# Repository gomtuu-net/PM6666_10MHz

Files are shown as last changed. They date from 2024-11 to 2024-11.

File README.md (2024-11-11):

# 10MHz OCXO for Philips/Fluke PM6666 counter
Alternative 10MHz oscillator for Philips/Fluke PM6665 and PM6666 frequency counters.

[Schematic](https://github.com/gomtuu-net/PM6666_10MHz/blob/master/PM6666-10MHz.pdf)

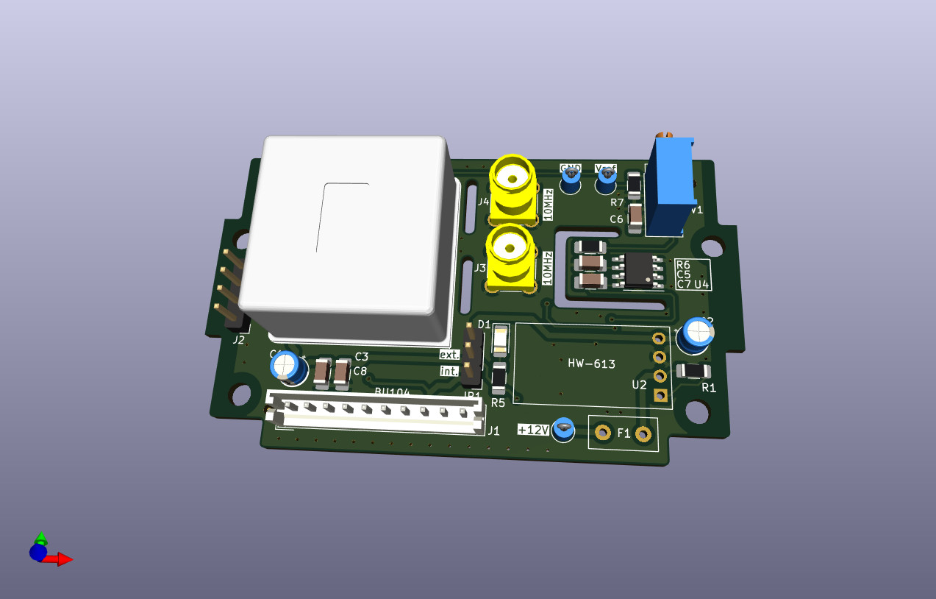
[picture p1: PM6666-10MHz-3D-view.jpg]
BoardTop 3D Board Top 3D


[Created with KiCAD ver. 7.0.11](https://kicad.org)

## Design ideas
* fuse/PTCC
* Vref with trim-pot for fine tune (Vc xtal: 0-4V)
* DC-DC conv (12V-to-5V)
* LCD-backlight power & trim-pot
* jumper to choose always-on or power-switch 
* SMA and Vref test-point
* 4 mount holes for alternative use
* status LED after fuse/DC-DC conv.
- temp.sensor under/near OCXO (LM35/DS18b20)
- Window-comparator with warm/cold LED indicator
- filter/circuit to convert square to sine-wave
- freq. divider
* currently usable OCXO: CTI OSC5A2B02 / NDK ENE3311B
- allow multiple footprints to fit other OCXO (ISOtemp/Vectron)

## Issues/todo
- Pk-Pk voltage from OCXO to high, need 470 load resistor
- change diameter hole for OCXO (0.8mm is to narrow)
- update/correct footprint thp Elco's (47uF & 100uF)
- improv. Vref tuning (20-turn trim-pot?)
- add solder-jumper to seperate 10MHz signal (antenne!)
- power-on LED at better location
- update part marking (pin.1, +, etc)

MHz.kHz.Hz
010.000.000
123.456.789

## Possible voltage references
- ADR4540		4.096V	2ppm	Vin: 4.2 - 15V
* LM4140		4.096V	3ppm	Vin: 5V
- LT1019-5		5.000V	5ppm
- LT1021		5.000V	5ppm	Vin: >10V
- MAX874		4.096V	20ppm	Vin: 4.3 - 20V
- MAX6070AAUT	4.096V	6ppm	Vin: 4.3 - 5.5V
- MAX6194A		4.500V	5ppm	Vin: 5 - 12.6V
* MAX6198A		4.096V	2ppm	Vin: 5 - 12.6V
- MAX6241		4.096V	5ppm	Vin: 8 - 36V
- MAX6341		4.096V	2.5ppm	Vin: 8 - 36V
- MAX6250BESA	5.000V	7ppm	
- REF5040		4.096V	3ppm	Vin: 4.3 - 18V

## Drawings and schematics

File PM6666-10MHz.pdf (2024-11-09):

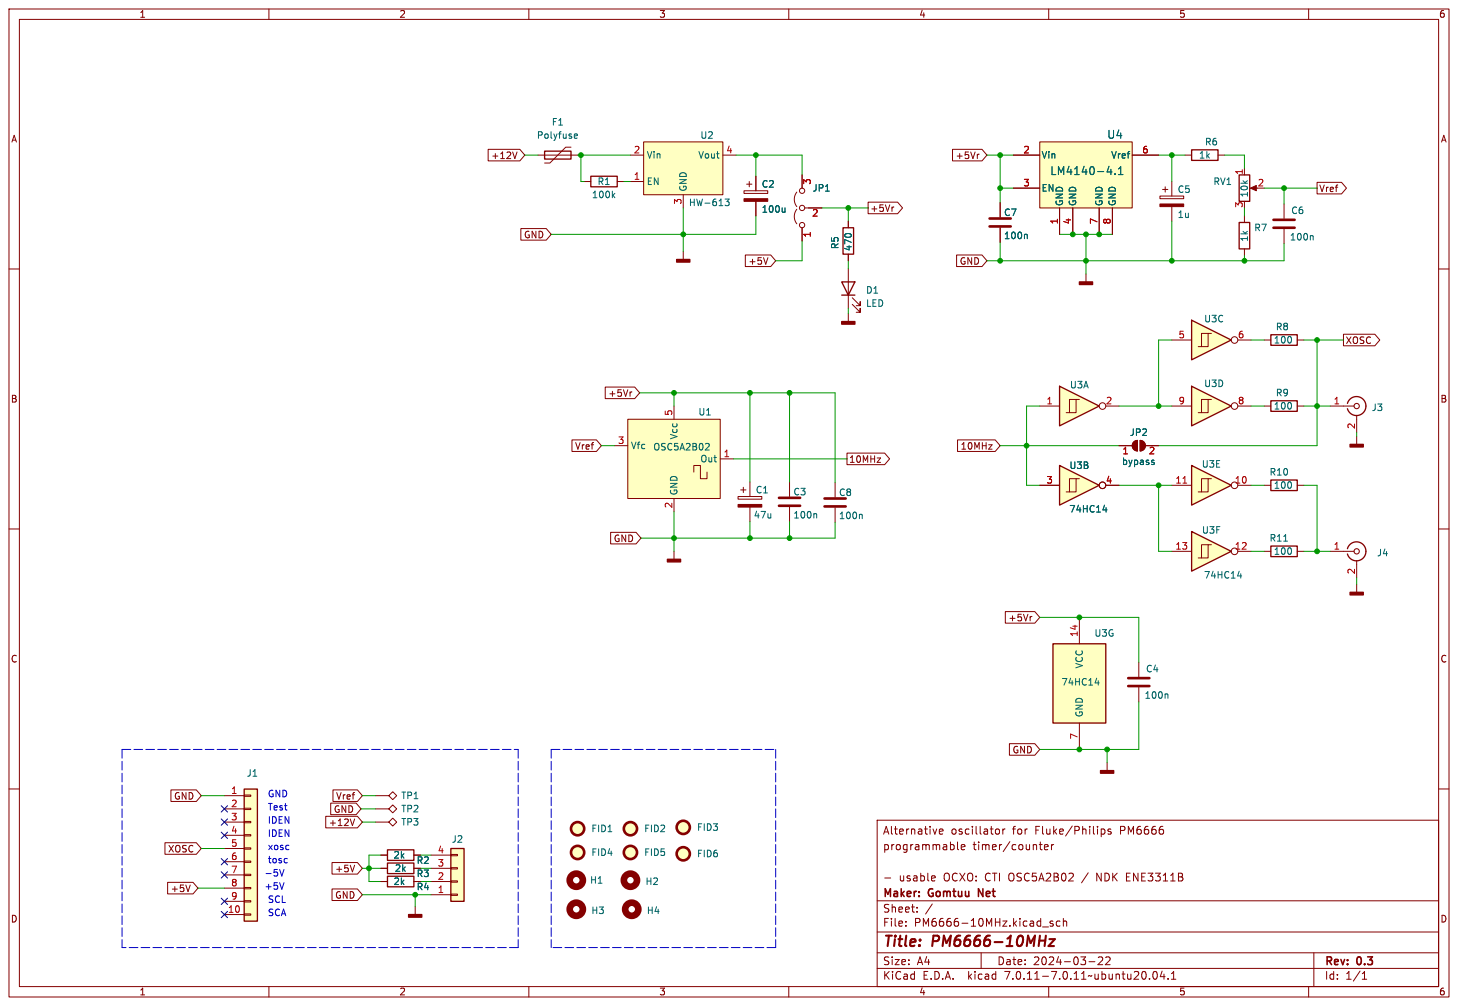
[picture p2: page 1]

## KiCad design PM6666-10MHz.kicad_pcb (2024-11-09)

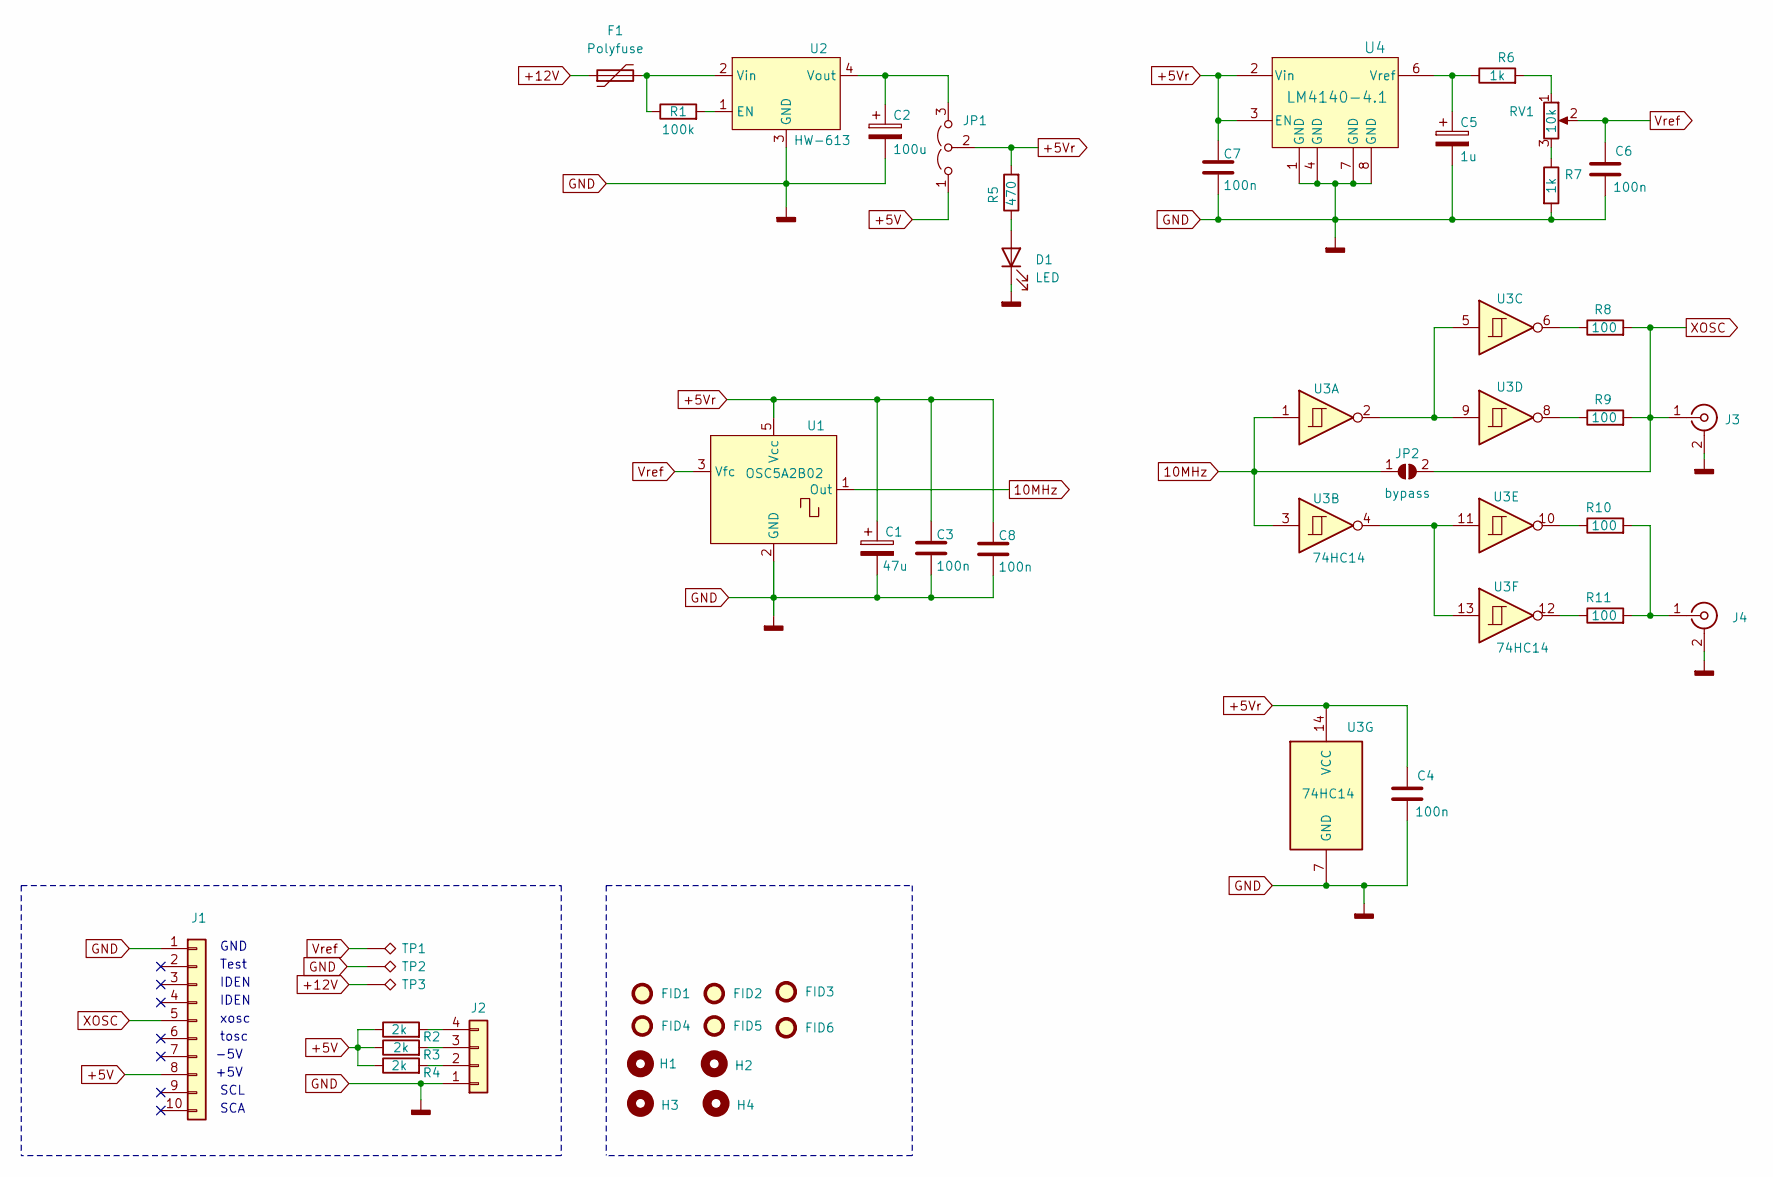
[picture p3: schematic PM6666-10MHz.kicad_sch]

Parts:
C1: 47u; CP_Radial_D4.0mm_P2.00mm
C2: 100u; CP_Radial_D4.0mm_P2.00mm
C3, C4, C6, C7, C8: 100n; C_1206_3216Metric_Pad1.33x1.80mm_HandSolder
C5: 1u; C_1206_3216Metric_Pad1.33x1.80mm_HandSolder
D1: LED; LED_1206_3216Metric_Pad1.42x1.75mm_HandSolder
F1: Polyfuse; Fuse_Littelfuse_395Series
FID1, FID2, FID3, FID4, FID5, FID6: Fiducial; Fiducial_0.5mm_Mask1.5mm
H1, H2, H3, H4: MountingHole; MountingHole_3.2mm_M3
J1: JST_EH_B10B-EH-A_1x10_P2.50mm_Vertical
J2: PinHeader_1x04_P2.54mm_Vertical
J3, J4: Conn_Coaxial; SMA_Amphenol_901-144_Vertical
JP1: PinHeader_1x03_P2.54mm_Vertical
JP2: bypass; SolderJumper-2_P1.3mm_Open_RoundedPad1.0x1.5mm
R1: 100k; R_1206_3216Metric_Pad1.30x1.75mm_HandSolder
R2, R3, R4: 2k; R_1206_3216Metric_Pad1.30x1.75mm_HandSolder
R5: 470; R_1206_3216Metric_Pad1.30x1.75mm_HandSolder
R6, R7: 1k; R_1206_3216Metric_Pad1.30x1.75mm_HandSolder
R8, R9, R10, R11: 100; R_1206_3216Metric_Pad1.30x1.75mm_HandSolder
RV1: 10k; Potentiometer_Bourns_3296Z_Horizontal
TP1: Vref; TestPoint_Loop_D1.80mm_Drill1.0mm_Beaded
TP2: GND; TestPoint_Loop_D1.80mm_Drill1.0mm_Beaded
TP3: +12V; TestPoint_Loop_D1.80mm_Drill1.0mm_Beaded
U1: OSC5A2B02; Oscillator_OCXO_OSC5A2B02
U2: HW-613; Convertor_DCDC_HW-613
U3: 74HC14; SO-14_3.9x8.65mm_P1.27mm
U4: LM4140-4.1; SOIC-8_3.9x4.9mm_P1.27mm

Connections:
10MHz: JP2.1 (A), U1.1 (Out), U3.1, U3.3
+5V: J1.8, JP1.1 (A), R2.1, R3.1, R4.1
+5Vr: C1.1, C3.1, C4.1, C7.1, C8.1, JP1.2 (C), R5.2, U1.5 (Vcc), U3.14 (VCC), U4.2 (Vin), U4.3 (EN)
+12V: F1.1, TP3.1
GND: C1.2, C2.2, C3.2, C4.2, C5.2, C6.2, C7.2, C8.2, D1.1 (K), J1.1, J2.1, J3.2 (Ext), J4.2 (Ext), R7.2, TP2.1, U1.2 (GND), U2.3 (GND), U3.7 (GND), U4.1 (GND), U4.4 (GND), U4.7 (GND), U4.8 (GND)
unnamed: D1.2 (A), R5.1
unnamed: J2.2, R4.2
unnamed: J2.3, R3.2
unnamed: J2.4, R2.2
unnamed: J4.1 (In), R10.2, R11.2
unnamed: C2.1, JP1.3 (B), U2.4 (Vout)
unnamed: R6.2, RV1.1
unnamed: R7.1, RV1.3
unnamed: R8.1, U3.6
unnamed: R9.1, U3.8
unnamed: R10.1, U3.10
unnamed: R11.1, U3.12
unnamed: R1.2, U2.1 (EN)
unnamed: F1.2, R1.1, U2.2 (Vin)
unnamed: U3.2, U3.5, U3.9
unnamed: U3.4, U3.11, U3.13
unnamed: C5.1, R6.1, U4.6 (Vref)
Vref: C6.1, RV1.2, TP1.1, U1.3 (Vfc)
XOSC: J1.5, J3.1 (In), JP2.2 (B), R8.2, R9.2

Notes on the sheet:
xosc
IDEN
SCL
tosc
GND
+5V
Test
SCA
-5V

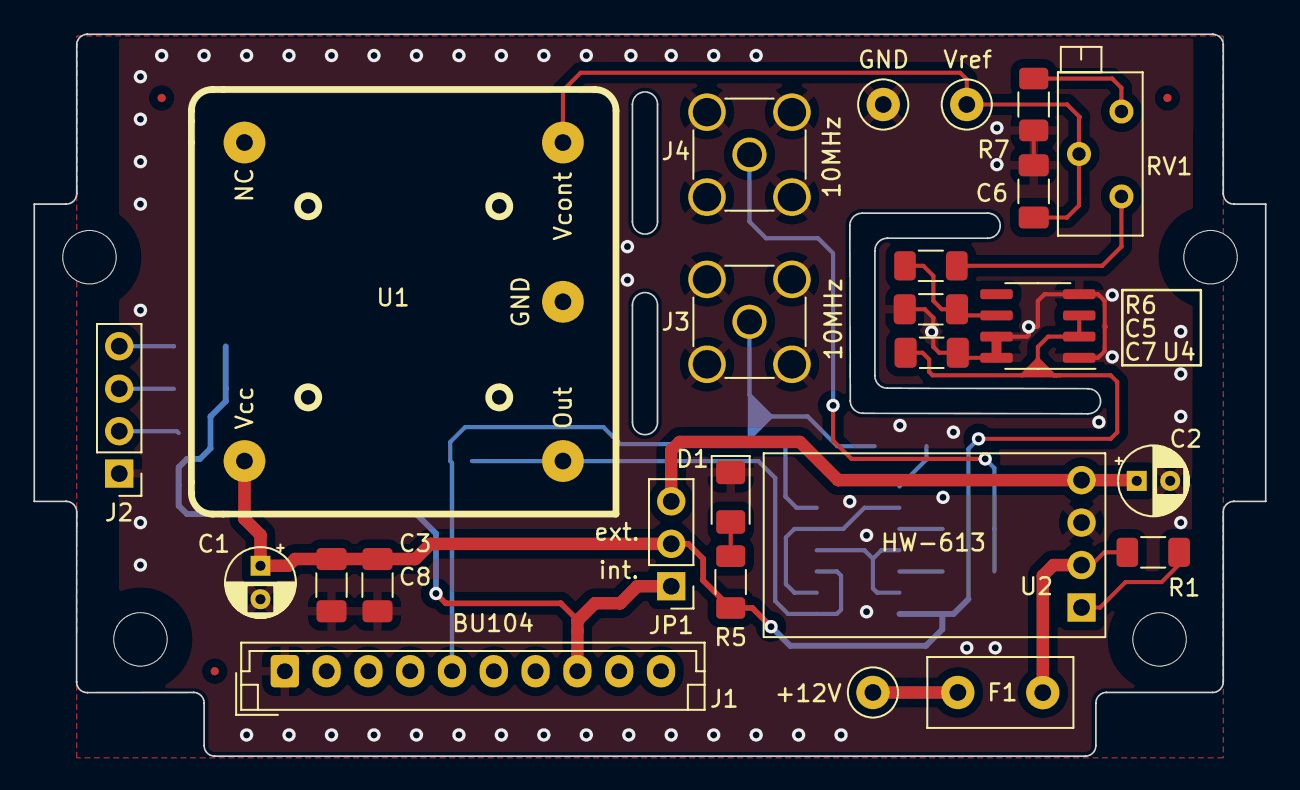
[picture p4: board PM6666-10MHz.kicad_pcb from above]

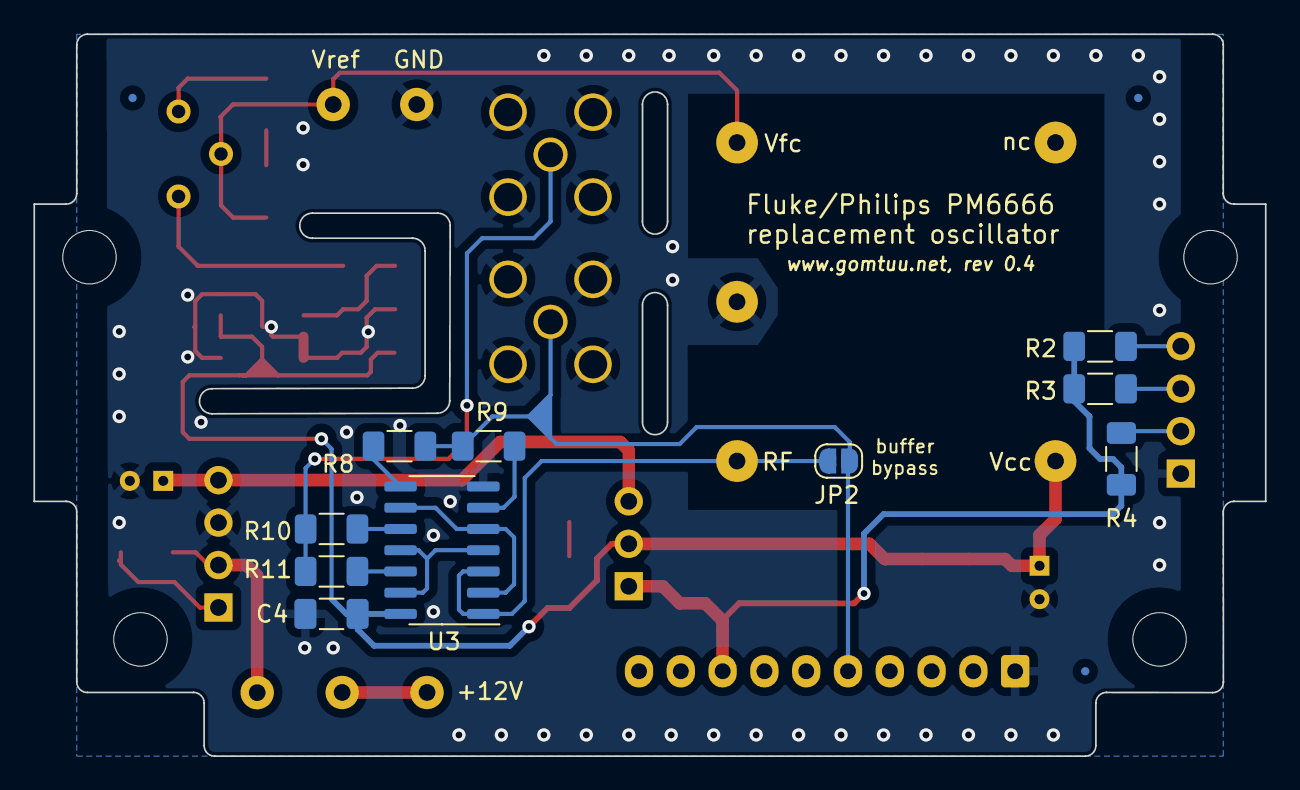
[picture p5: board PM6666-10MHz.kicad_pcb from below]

Board: 2 copper layers, 73.7 x 43.2 mm, 45 parts (13 on the bottom side), 24 nets.

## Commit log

2024-11-09 Add files via upload
    Initial commit.
    [PM6666-10MHz.kicad_pcb, PM6666-10MHz.kicad_sch, PM6666-10MHz.sch]
2024-11-11 Add files via upload
    Adding schematic in PDF format
2024-11-11 Add files via upload
    Adding 3D view of the final PCB
